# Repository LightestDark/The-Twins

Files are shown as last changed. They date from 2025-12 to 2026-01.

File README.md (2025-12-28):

# The-Twins

Overview: 80 key fully backlight split keyboard, with a 0.96 inch oled each side to display vital info about the the keyboard whilst using. Powered with a 3.5V battery





3D PARTS:



PCB:



3D View:



Schematic:



Bill of Materials:

2 x XIAO-nRF52840-SMD

40 x 1N5819 SMD Diodes

40 x MX-Style switches

40 x Blank DSA keycaps

42 x SK6812-E Reverse Mount LEDs

4 x Resistors (1 806k, 1 2M)

12 x M3x10 Screws

12 x M3x5mx4mm heatset inserts

40 x Kailh hotswappable sockets

2 x 0.96 inch OLED 

1 x Case (6 3D printed parts - 3 left/right)

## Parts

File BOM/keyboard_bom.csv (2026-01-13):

Qty (used) | Value | Footprint / Notes | References / Notes | Source / Link | Pack Qty | Price (pack) | Full Pack Cost Used
2 | R1 (806 kΩ) | Resistor_SMD:R_0805_2012Metric | 806K1, 806K2 | https://jlcpcb.com/product/sku/C23250 | 20 | $0.0240 | $0.0240
2 | R2 (2.2 MΩ) | Resistor_SMD:R_0805_2012Metric | 2M1, 2M2 | https://jlcpcb.com/product/sku/C26113 | 20 | $0.0520 | $0.0520
40 | 1N5819 Diode | Diode_SMD:D_SOD‑123 | D1–D40 | https://www.aliexpress.us/item/3256809168494688.html | 100 | $3.18 | $1.27
40 | SK6812MINI‑E LED | SKNEW:SK6812MINI-E_fixed | D41–D80 | https://jlcpcb.com/product/sku/C5149201 | 100 | $6.9100 | $6.9100
40 | MX Brown Keys | PCM_marbastlib-mx:SW_MX_HS_CPG151101S11_1u | SW1–SW40 | https://www.aliexpress.com/item/1005008998414457.html | 60 | $16.25 | $16.25
2 | OLED_DISPLAY | Connector_PinHeader_2.54mm:PinHeader_1x04_P2.54mm | J1, J2 | https://www.aliexpress.us/item/3256806486516851.html | 3 | $6.05 | $6.05
2 | XIAO-nRF52840-SMD | OPL:modified-XIAO-nRF52840-SMD | U1, U2 | https://www.seeedstudio.com/Seeed-XIAO-BLE-nRF52840-p-5201.html | 2 | $12.05 | $24.10
70 | Hot-swap sockets (Kailh) | Mechanical keyboard hot-swap sockets | - | https://www.aliexpress.com/item/1005008954571807.html | 70 | $1.00 | $1.00
2 | Rubber mat | Standalone part | - | https://www.amazon.co.uk/4PCS-Enhanced-Cuttable-Rubber-Grip/dp/B0F32WG6FG | 4 | $6.42 | $6.42
2 | Foam sheet | Standalone part | - | https://www.aliexpress.us/item/3256805908759047.html | 2 | $2 | $2
8 | Neodymium magnet 5mm | Standalone part | - | https://www.aliexpress.us/item/3256809168494688.html | 8 | $1 | $1
2 | On/Off switch | Standalone part | SW_A, SW_B | https://www.aliexpress.us/item/3256807128995360.html | 10 | $1 | $1
1 | JLCPCB PCB | 2-layer split keyboard PCB | - | https://jlcpcb.com/ | 1 | $20.95 | $20.95
1 | 3D Printed Case | 6-part case for split keyboard | - | Standalone / Buy Separately | 1 | $10 | $10
 |  | TOTAL COST | - | - | - | - | $97.88

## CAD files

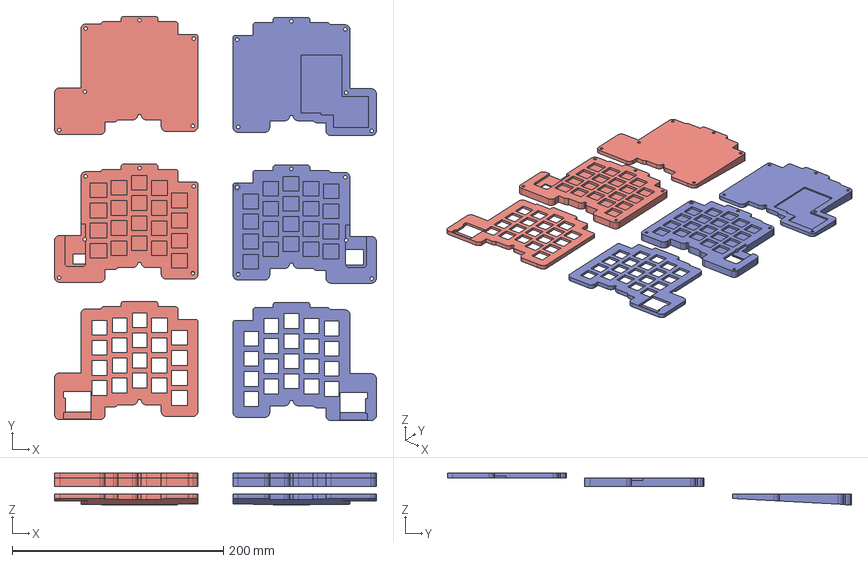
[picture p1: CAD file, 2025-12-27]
CAD/3D Printed Parts only.step
304.8 x 382.7 x 29.9 mm

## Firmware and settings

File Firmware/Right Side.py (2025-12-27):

import board
from kmk.kmk_keyboard import KMKKeyboard
from kmk.scanners import DiodeOrientation
from kmk.keys import KC
from kmk.modules.split import Split, SplitType, SplitSide
from kmk.extensions.RGB import RGB
from kmk.extensions.oled import OLED
from kmk.extensions.oled.ssd1306 import SSD1306
from analogio import AnalogIn

# ----------------- LED & helper -----------------
class LedManager:
    def __init__(self, keyboard, fade_steps=6):
        self.keyboard = keyboard
        self.fade_steps = fade_steps
        self.active = {}

    def press(self, index, hsv):
        self.active[index] = [self.fade_steps, hsv]
        self.keyboard.rgb.set_hsv(*hsv, index)

    def release(self, index):
        if index in self.active:
            self.active[index][0] = self.fade_steps

    def update(self):
        for idx, data in list(self.active.items()):
            steps, (h, s, v) = data
            if steps <= 0:
                self.keyboard.rgb.set_hsv(h, s, 0, idx)
                del self.active[idx]
            else:
                brightness = int(v * steps / self.fade_steps)
                self.keyboard.rgb.set_hsv(h, s, brightness, idx)
                data[0] -= 1
        self.keyboard.rgb.show()


class LedKey(KC):
    def __init__(self, key, led_index, hue=280, sat=255, val=255):
        self.key = key
        self.led_index = led_index
        self.hsv = (hue, sat, val)

    def on_press(self, keyboard, coord_int=None):
        keyboard.add_key(self.key)
        keyboard.led_manager.press(self.led_index, self.hsv)

    def on_release(self, keyboard, coord_int=None):
        keyboard.remove_key(self.key)
        keyboard.led_manager.release(self.led_index)


# ----------------- Keyboard -----------------
keyboard = KMKKeyboard()

# Matrix pins
keyboard.col_pins = (board.D1, board.D2, board.D3, board.D4, board.D5, board.D6, board.D7, board.D8)
keyboard.row_pins = (board.D9, board.D10, board.D11, board.D12, board.D13)
keyboard.diode_orientation = DiodeOrientation.COL2ROW

# Split BLE
keyboard.modules.append(Split(split_type=SplitType.BLE, split_side=SplitSide.RIGHT))

# RGB
keyboard.extensions.append(
    RGB(pixel_pin=board.NFC1, num_pixels=42, rgb_order=(1,0,2),
        hue_default=0, sat_default=255, val_default=255, val_limit=255)
)

# LED manager
keyboard.led_manager = LedManager(keyboard)
def before_matrix_scan(kbd):
    kbd.led_manager.update()
keyboard.before_matrix_scan = before_matrix_scan

# OLED
oled = OLED(sda=board.SDA, scl=board.SCL, driver=SSD1306, flip=False)
keyboard.extensions.append(oled)

# ----------------- Battery -----------------
battery_adc = AnalogIn(board.A0)
R1 = 806_000
R2 = 2_000_000

def get_batt_voltage():
    raw = battery_adc.value
    v_adc = (raw / 65535) * 3.3
    return v_adc * (R1 + R2) / R2

def battery_percent():
    v = get_batt_voltage()
    return max(0, min(100, int((v - 3.0) / (4.2 - 3.0) * 100)))

# OLED update
def oled_update(kbd):
    oled.fill(0)
    oled.text("Right Half",0,0)
    ble_status = "OK" if getattr(kbd,'is_ble_connected',False) else "OFF"
    oled.text(f"BLE: {ble_status}",0,10)
    oled.text(f"Batt: {battery_percent()}%",0,20)
    oled.show()

keyboard.before_matrix_scan.append(oled_update)

# LED mapping
led_index_map = list(range(42))

# Keymap
keys = [
    KC.N6, KC.N7, KC.N8, KC.N9, KC.N0, KC.MINUS, KC.EQUAL, KC.BSLASH,
    KC.Y, KC.U, KC.I, KC.O, KC.P, KC.LBRC, KC.RBRC, KC.SCLN,
    KC.H, KC.J, KC.K, KC.L, KC.QUOTE, KC.ENTER, KC.UP, KC.DEL,
    KC.N, KC.M, KC.COMMA, KC.DOT, KC.SLASH, KC.LEFT, KC.DOWN, KC.RIGHT,
    KC.NO, KC.NO, KC.RCTRL, KC.RALT, KC.RSHIFT, KC.SPACE, KC.BSPACE, KC.ENTER
]
keyboard.keymap = [[LedKey(k, led_index_map[i]) for i,k in enumerate(keys)]]

if __name__=="__main__":
    keyboard.go()

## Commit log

2025-12-27 Create The Twins.pcb
2025-12-27 Create Split Keyboard.drl
    [Split Keybaord.drl]
2025-12-27 Rename Split Keybaord.drl to Split Keyboard.drl
    [Split Keyboard.drl]
2025-12-27 Create Assembly
